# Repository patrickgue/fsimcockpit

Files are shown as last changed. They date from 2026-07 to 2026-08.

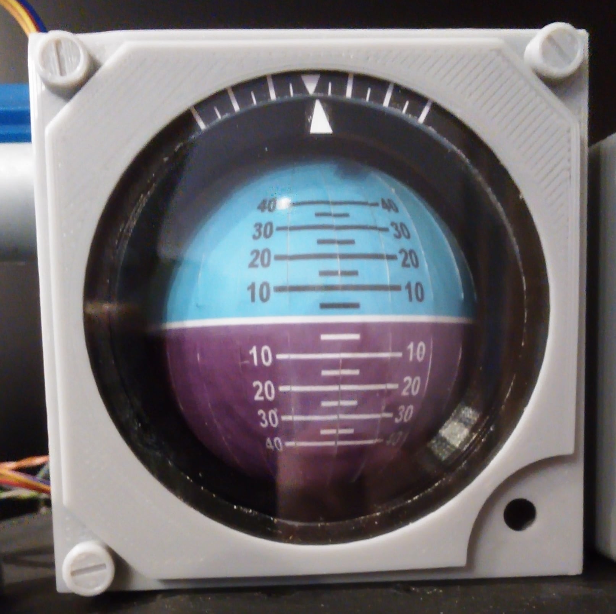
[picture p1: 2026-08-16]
Models/ai/images/Attitude_Indicator_printed.jpg

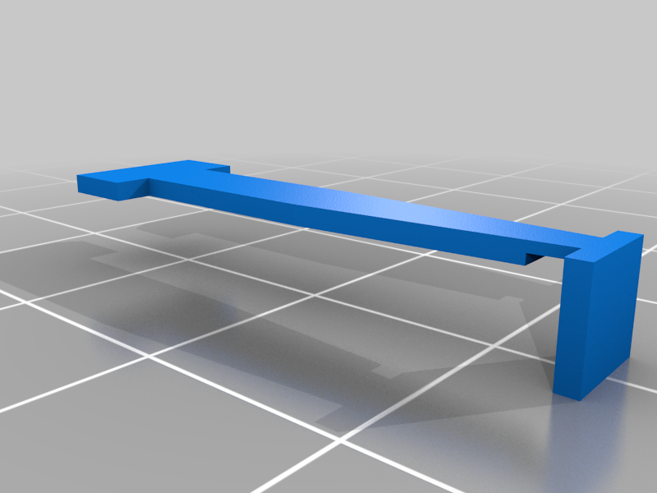
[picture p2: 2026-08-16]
Models/ai/images/964544c1647295031b2b73cd0fc1d7ba.png

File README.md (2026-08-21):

---
title: FSimCockpit
---

Software and Hardware for building a home cockpit with 3d printed "steam gauge" instruments

Components:

* Windows App: Connects to MSFS to read out instrument data. Send this data to the microcontroller via the serial connection. This is built using C# and provides a WPF GUI for instrument calibration.
* Microcontroller: Drive servos and stepper motors for the instrument. Arduino Mega based.
  * Parse instrument data from serial data coming from the windows application
* 3D models for printing, assembly

# Distribution

If not mentioned otherwise, this project is licensed under the MIT license. A copy of the license text is provided in the LICENSE file.

Following external components are used: (License file provided in the subfolder)

* Attitude Indicator (hein4bloed, CC-BY-NC)
* Vertical Speed indicator (Bacab, CC-BY-NC-SA)
* Turn coordinator (Bacab, CC-BY-NC-SA)

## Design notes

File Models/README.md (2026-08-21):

Servos and Steppers:

| **Instrument** | **Steppers** | **Servo** |
|---|---|---|
| VSI | 0 | 1 |
| HI | 1 | 0 |
| SPEED | 0 | 1 |
| ALT | 3 | 0 |
| TC | 0 | 2 |
| AI | 2 | 0 |

Sum: 5 Steppers, 4 Servos

## Vertical Speed Indicator (VSI)

Works as provided from thingiverse. Following things have to be added or modified:

* Adapter to connect gear to servo (`servo_gear_connector.scad`)
* Standoff; This is mentioned in the instruction. Either metal standoffs with threads can be used. Otherwise there are 3d printed standoffs provided (`Standoff.scad`)
* The hole on the front plate and the pointer have to be widened by grinding.

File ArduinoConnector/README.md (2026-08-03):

Data Table

| **Indication** | **Code** | **Description** |
|---|---:|---|
| VSI | 0x10 | vertical speed in ft/min |
| VSI_CALIBR_ZERO | 0x11 | in degrees (stepper) |
| VSI_CALIBR_PLUS5 | 0x12 | in degrees (stepper) |
| VSI_CALIBR_MINUS5 | 0x13 | in degrees (stepper) |
| HI | 0x20 | Heading Indicator in degrees |
| HI_CALIBR_ZERO, | 0x21 | in degrees (servo) |
| SPEED | 0x30 | airspeed in kt |
| SPEED_CALIBR_ZERO | 0x31 | in degrees (servo) |
| SPEED_CALIBR_HUNDRED | 0x32 | in degrees (servo) |
| ALT | 0x40 | altitude in ft |
| ALT_CALIBR_HUNDREDS_ZERO | 0x41 | in steps (stepper) |
| ALT_CALIBR_THOUSANDS_ZERO | 0x42 | in steps (stepper) |
| ALT_CALIBR_TENTHOUSANDS_ZERO | 0x43 | in steps (stepper) |
| TS_TURN | 0x50 | turn indicator in turns / 2*minute |
| TS_TURN_CALIBR_ZERO | 0x51 | in degrees (servo) |
| TS_TURN_CALIBR_LEFTTURN | 0x52 | in degrees (servo) |
| TS_TURN_CALIBR_RIGHTTURN | 0x53 | in degrees (servo) |
| TS_SLIP | 0x54 | slip indicator (-1.0 left, 1.0 right) |
| TS_SLIP_CALIBR_ZERO | 0x55 | in degrees (servo) |
| TS_SLIP_CALIBR_LEFT | 0x56 | in degrees (servo) |
| TS_SLIP_CALIBR_RIGHT | 0x57 | in degrees (servo) |
| AI_PITCH | 0x60 | attitude indicator (degrees) |
| AI_PITCH_CALIBR_20ZERO | 0x61 | in steps (stepper) |
| AI_PITCH_CALIBR_20UP | 0x62 | in steps (stepper) |
| AI_PITCH_CALIBR_20DOWN | 0x63 | in steps (stepper) |
| AI_ROL | 0x64 | attitude roll (degrees) |
| AI_ROL_CALIBR_20ZERO | 0x65 | in steps (stepper) |
| AI_ROL_CALIBR_20LEFT | 0x66 | in steps (stepper) |
| AI_ROL_CALIBR_20RIGHT | 0x67 | in steps (stepper) |
| ERROR | 0xFF | Invalid, should not occur |

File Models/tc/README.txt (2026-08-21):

Turn coordinator for flight simulator by Bacab on Thingiverse: https://www.thingiverse.com/thing:6554762

Summary:
This is a replica of a turn coordinator as can be found in nearly all general aviation aircrafts. It is designed to be used with two servo-motors (SG90 like)The PDF is the background to be printed and glued to the front plane.I will use it with an Arduino Uno. I plan on using it for DCS World through the use of DCS Bios.To assemble the different parts you will need 4 M3 screws (M3x10mm), 4 spacers (M3x30 mm) and four M3 nuts to attach the front face to the motor support. The servo-motors are attached using the M2 screws that came with them. You will also need a M2.5 screw to attach the ball (M2.5x5 mm) to the upper servo and one M2.5x20mm screw and two nuts to attach the aircraft to the second, lower, servo. The two nuts are used one against the other to block in the correct position the aircraft silhouette.

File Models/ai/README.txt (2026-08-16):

B737 Attitude Indicator by hein4bloed on Thingiverse: https://www.thingiverse.com/thing:1991135

Summary:
Use two 28BYJ-48 stepper motors and Arduino with Mobiflight Software. Works great!Read out FSX FSUIPC Pitch Offset 2F70 and Bank Offset 2F78.

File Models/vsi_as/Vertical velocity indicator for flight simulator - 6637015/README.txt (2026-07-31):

Vertical velocity indicator for flight simulator by Bacab on Thingiverse: https://www.thingiverse.com/thing:6637015

Summary:
This is a replica of a vertical velocity indicator as can be found in nearly all general aviation aircrafts. It is designed to be used with one servo-motor (SG90 like)The PDF is the background to be printed and glued to the front plate.I will use it with an Arduino Uno. I plan on using it for DCS World through the use of DCS Bios.To assemble the different parts you will need 4 M3 screws (M3x10mm), 4 M3 spacers (20mm) and 4 M3 nuts to attach the front face to the motor support. The servo-motor is attached using the M2 screws that came with it. You will also need a M2.5 screw to attach the servo gear (M2.5x5 mm) to the servo. The needle should be glued to the needle gear ONCE assembled with the front plate : the gear is on the back of the front plate, the needle on the other side.

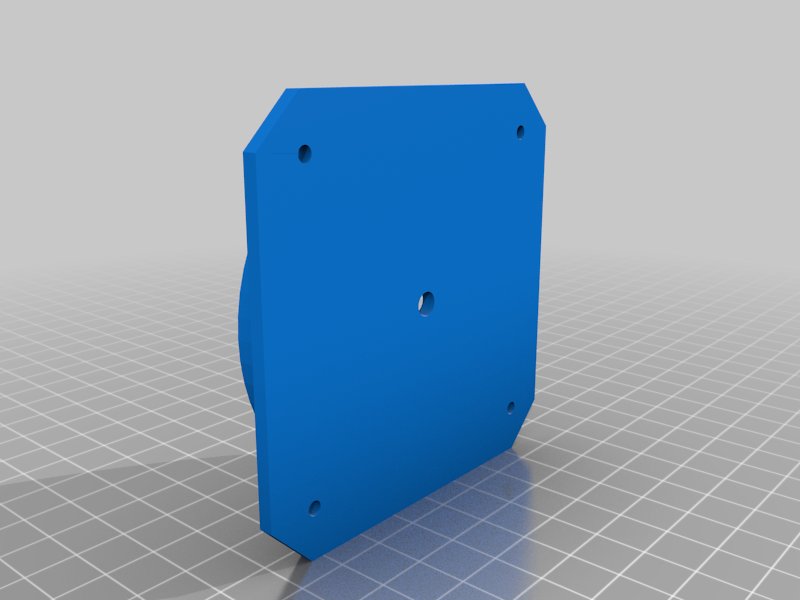
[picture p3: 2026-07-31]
Models/vsi_as/Vertical velocity indicator for flight simulator - 6637015/images/0cd2b5fc-27c4-4e6a-b78b-81af9a082db9.png

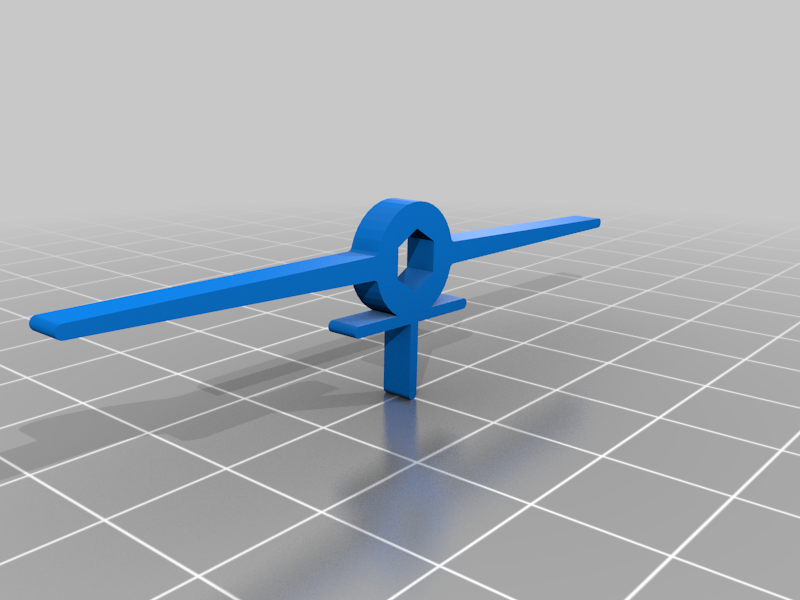
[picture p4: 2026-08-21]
Models/tc/images/5e0f1487-dd2c-4491-b8d7-2c6afee6cf06.png

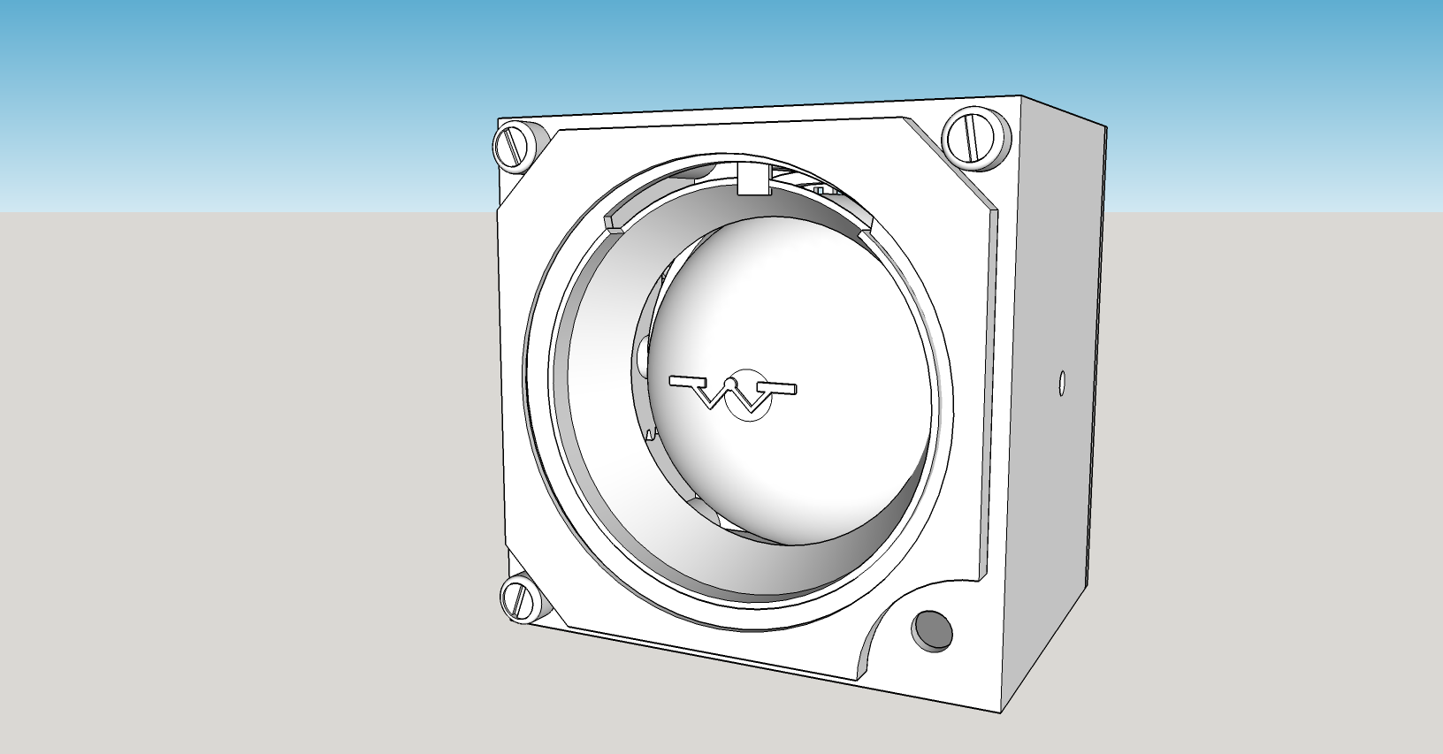
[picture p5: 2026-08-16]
Models/ai/images/Attitude_indicator1.png

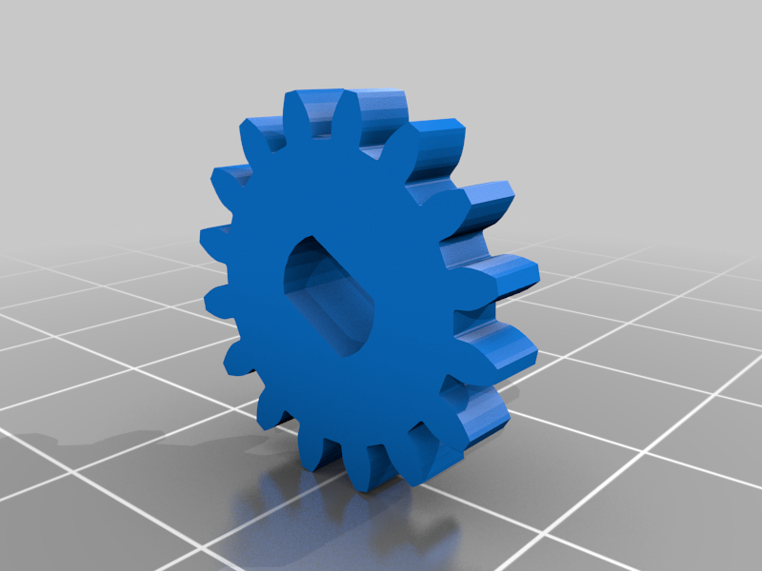
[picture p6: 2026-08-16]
Models/ai/images/55b75d970b0fac53f8fbcc01d031f647.png

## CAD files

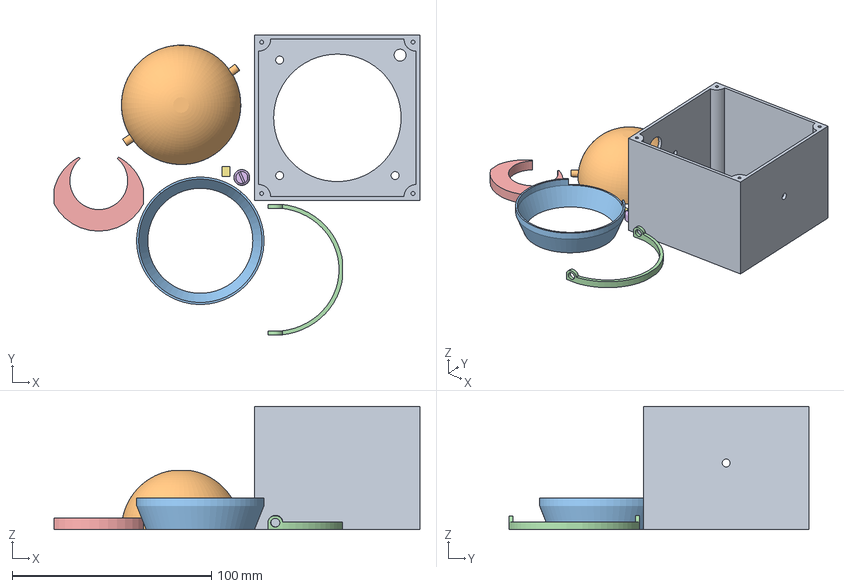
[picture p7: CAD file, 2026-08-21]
Models/ai/Attitude_indicator.3mf
183.8 x 150.5 x 62.0 mm
Gehaeuse.stl
Attitude_indicator.stl
Blende_innen.stl
Buegel.stl
Motorhalter.stl
Schraube.stl
Zeigerblaettchen.stl

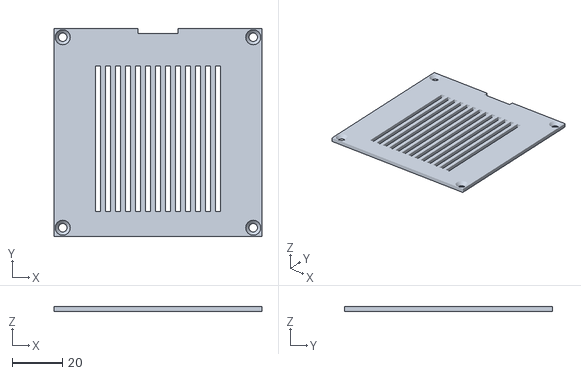
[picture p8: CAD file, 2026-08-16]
Models/ai/files/Rückwand.stl
83.0 x 83.0 x 2.00

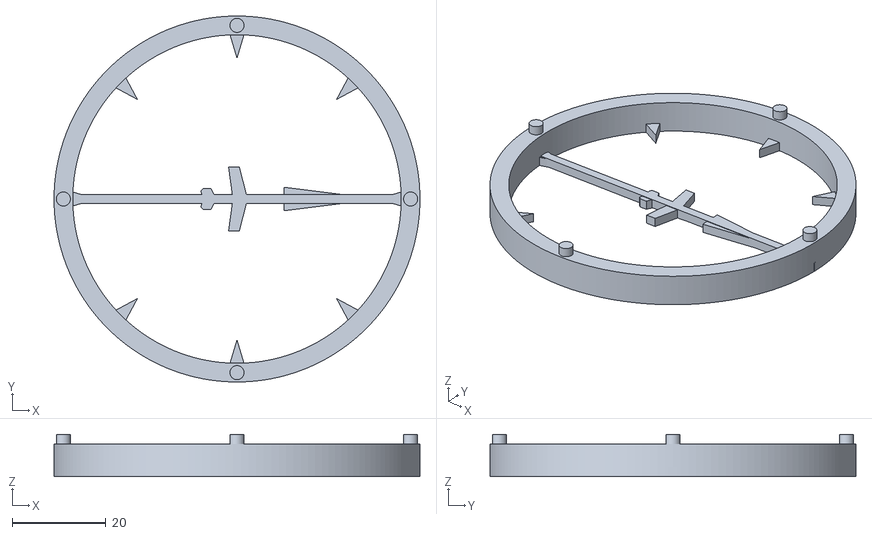
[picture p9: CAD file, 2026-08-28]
Models/hi/hi_face.stl
78.0 x 78.0 x 9.00

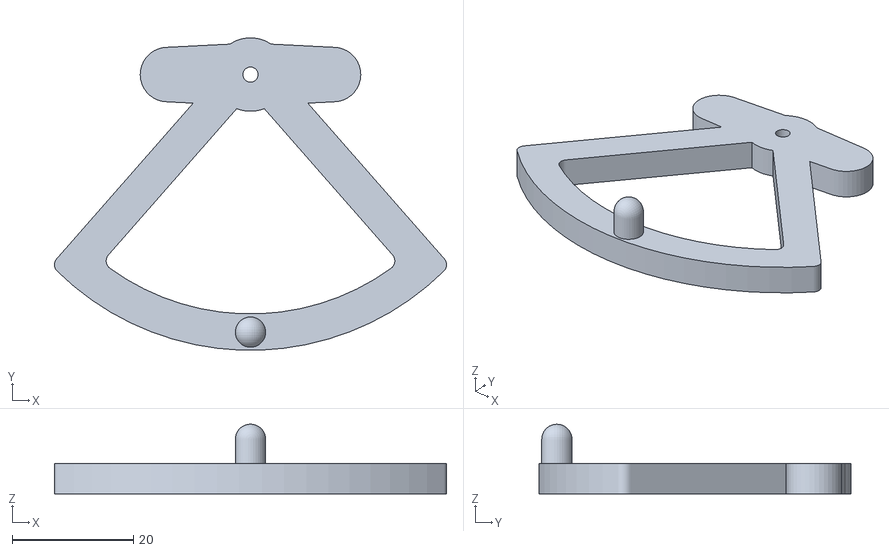
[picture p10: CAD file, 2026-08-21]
Models/tc/files/ball.STL
64.7 x 51.5 x 11.5

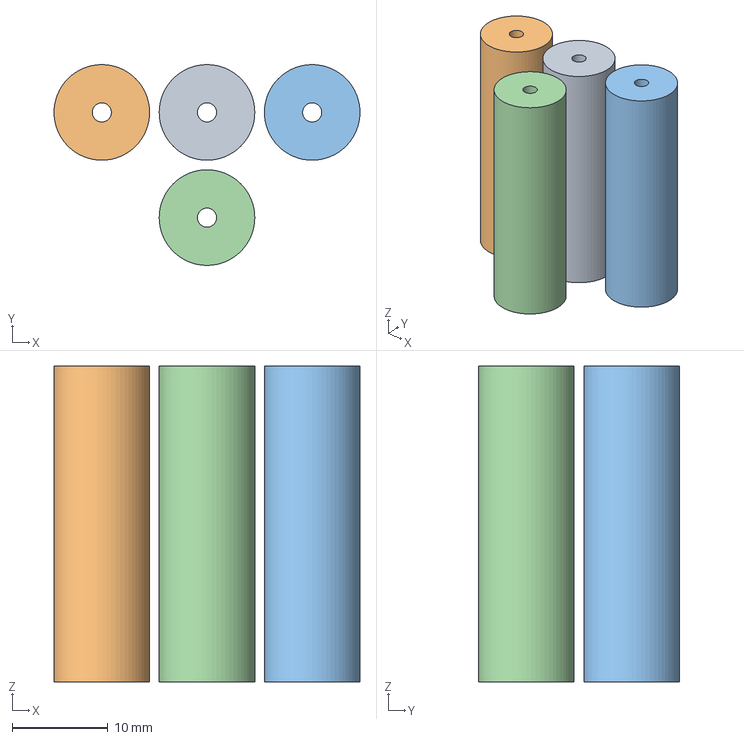
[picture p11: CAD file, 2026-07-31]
Models/vsi_as/standoffs.3mf
32.0 x 21.0 x 33.0 mm
standoffs.stl x 4

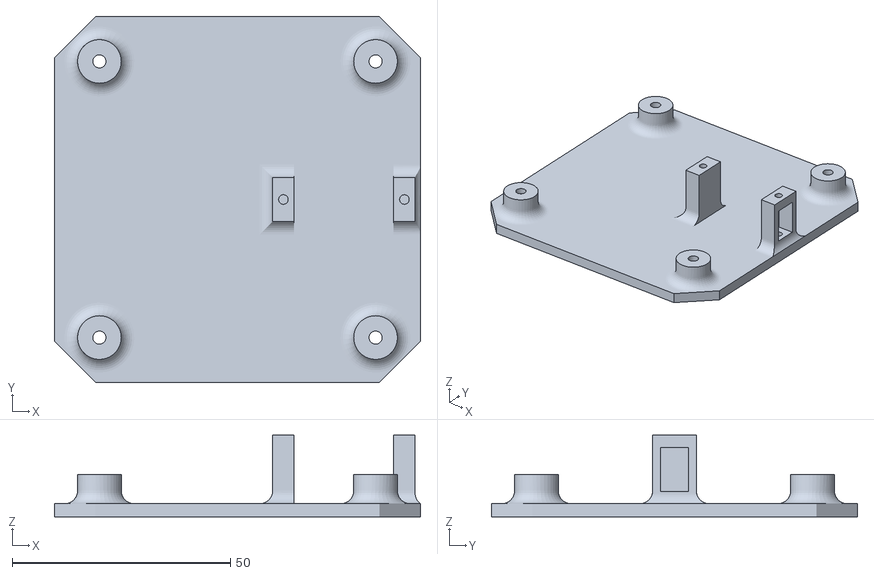
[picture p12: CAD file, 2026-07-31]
Models/vsi_as/Vertical velocity indicator for flight simulator - 6637015/files/back_plate_VVI.STL
83.8 x 83.8 x 18.7

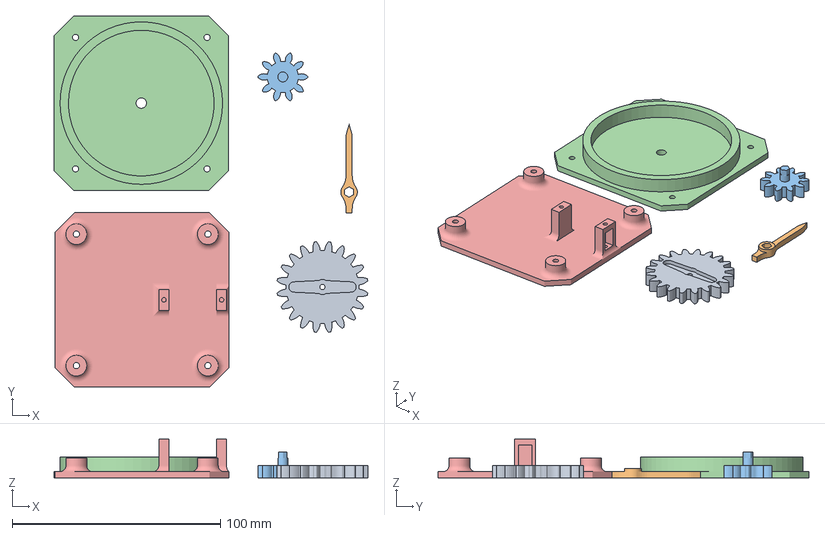
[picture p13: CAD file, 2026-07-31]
Models/vsi_as/Vertical velocity indicator for flight simulator - 6637015/servo_gear.3mf
150.8 x 178.4 x 18.7 mm
servo_gear.STL
needle_VVI.STL
needle_gear.STL
front_plate_VVI.STL
back_plate_VVI.STL

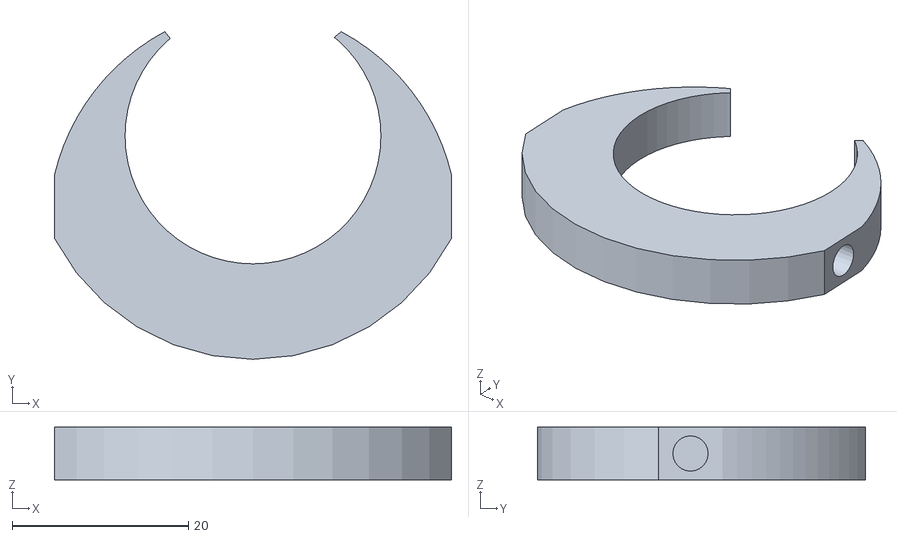
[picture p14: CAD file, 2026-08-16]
Models/ai/files/Motorhalter.stl
45.0 x 37.1 x 6.00

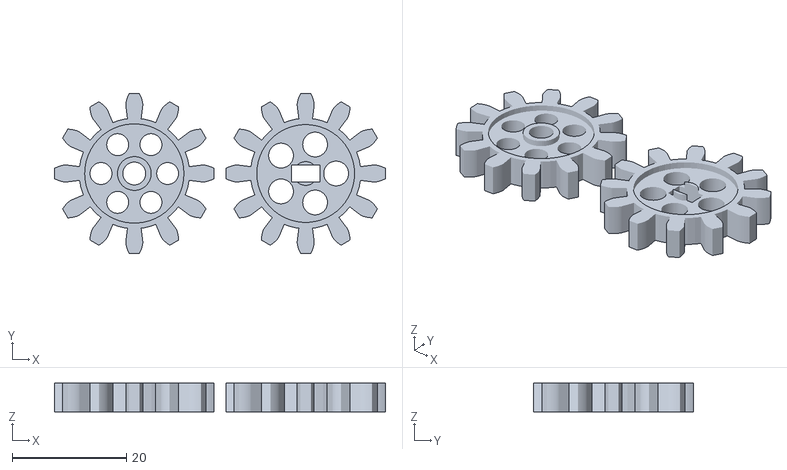
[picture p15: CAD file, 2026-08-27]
Models/hi/gear.stl
57.9 x 27.9 x 5.00

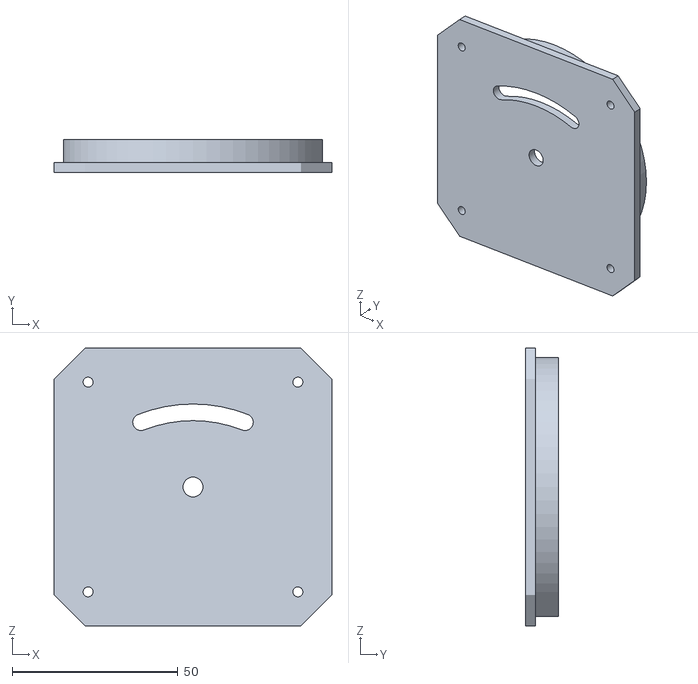
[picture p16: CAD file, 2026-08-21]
Models/tc/files/front_plane.STL
83.8 x 10.0 x 83.8

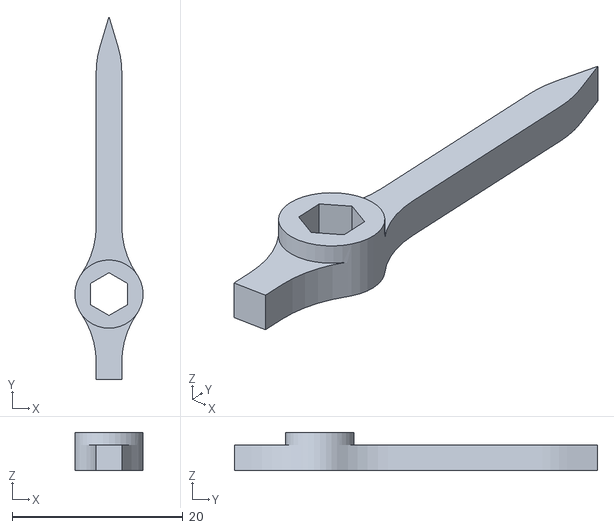
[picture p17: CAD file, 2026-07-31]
Models/vsi_as/Vertical velocity indicator for flight simulator - 6637015/files/needle_VVI.STL
8.00 x 42.5 x 4.50

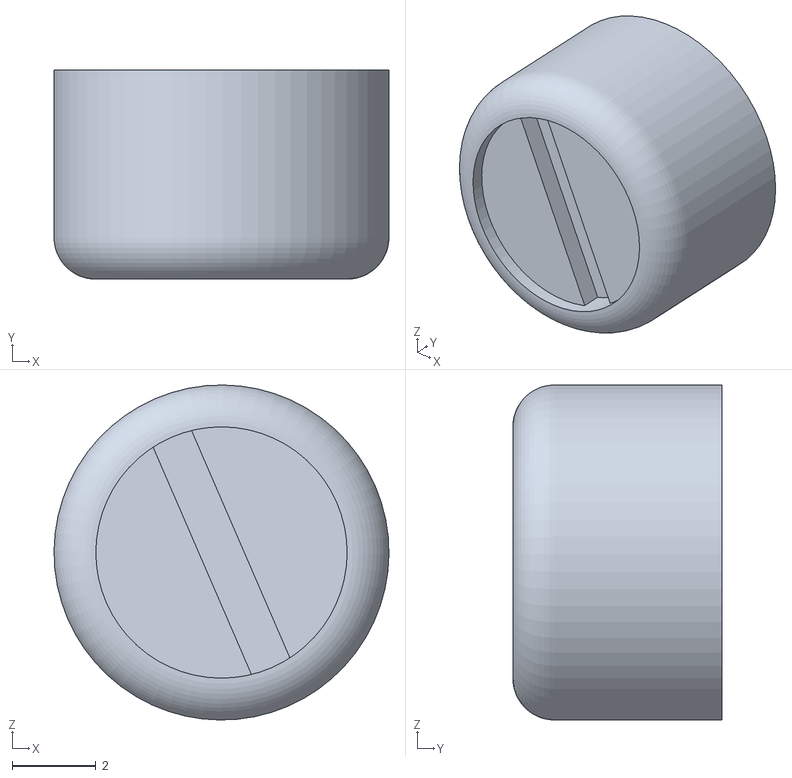
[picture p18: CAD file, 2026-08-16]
Models/ai/files/Schraube.stl
8.00 x 5.00 x 8.00

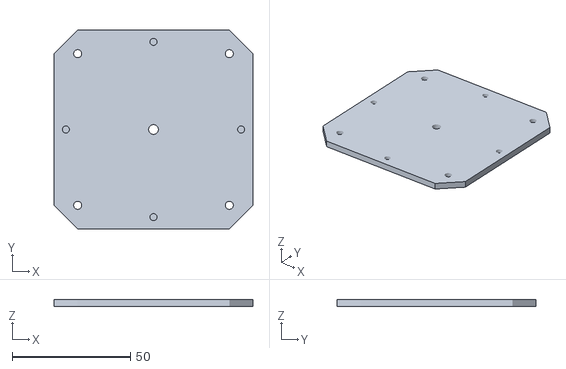
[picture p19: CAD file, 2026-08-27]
Models/hi/hi_front.stl
84.0 x 84.0 x 3.00

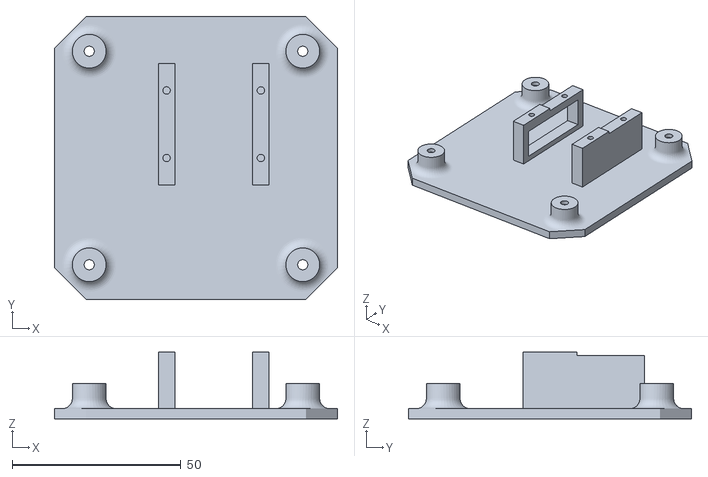
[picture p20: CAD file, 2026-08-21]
Models/tc/files/servo_support.STL
83.8 x 83.8 x 19.7

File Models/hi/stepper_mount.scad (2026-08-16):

$fn=30;

screw_offset=32;
stepper_screw_offset=35/2;
difference() {
    union() {
        // four main pillars
        for (i = [-screw_offset:2*screw_offset:screw_offset]) {

                translate([i, screw_offset, 0]) {
                    cylinder(d=6,h=7.5);
                }
        }
        // stepper mounting bracket
        translate([0,screw_offset + .5,4+(3.5/2)])
            cube([2*screw_offset + 6, 7, 3.5],center=true);
        
        
    }

    for (i = [-screw_offset:2*screw_offset:screw_offset]) {
        translate([i, screw_offset, 0])
            cylinder(d=3,h=8);
    }
    
    
    // additional space for gear
    translate([0,screw_offset,4])
        cube([28,8,2],center=true);
    
    for (i = [-stepper_screw_offset:2*stepper_screw_offset:stepper_screw_offset]) {
        translate([i, screw_offset + 1, 0])
            cylinder(d=3,h=8);
    }
}

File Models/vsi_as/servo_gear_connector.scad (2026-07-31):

$fn=60;

difference() {
union() {
cube([28,4,1], center= true);
translate([0,0,0.5])
cylinder(d=6.5,h=2,center=true);
translate([14,0,0])
    cylinder(d=4,h=1,center=true);
translate([-14,0,0])
    cylinder(d=4,h=1,center=true);
}
cylinder(d=2, h=4, center=true);
translate([0,0,1])
cylinder(d=4.8, h=1, center=true);
}

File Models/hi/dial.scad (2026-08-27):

$fn=150;
cylinder(d=68, h=1);
cylinder(d=3.8, h=8);

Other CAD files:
Models/vsi_as/Vertical velocity indicator for flight simulator - 6637015/files/front_plate_VVI.STL
Models/ai/files/Kugelstift.stl
Models/hi/dial.stl
Models/tc/files/aircraft.STL
Models/hi/gear.scad
Models/ai/files/Attitude_indicator.stl
Models/ai/files/Attitude_indicator1.skp
Models/ai/files/Blende_innen.stl
Models/ai/files/Buegel.stl
Models/ai/files/Frontblend.stl
Models/ai/files/Gehaeuse.stl
Models/ai/files/Horizontmarkierung.stl
Models/ai/files/Zahnrad1.stl
Models/ai/files/Zahnrad2.stl
Models/ai/files/Zeiger.stl
Models/ai/files/Zeigerblaettchen.stl
Models/alt/alt_A.3mf
Models/alt/alt_front.scad
Models/alt/alt_front.stl
Models/alt/alt_needle_100.scad
Models/alt/alt_needle_100.stl
Models/alt/alt_needle_1000.scad
Models/alt/alt_needle_1000.stl
Models/alt/alt_needle_10000.scad
Models/alt/alt_needle_10000.stl
Models/alt/gear_100.scad
Models/alt/gear_100.stl
Models/alt/gear_1000.scad
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

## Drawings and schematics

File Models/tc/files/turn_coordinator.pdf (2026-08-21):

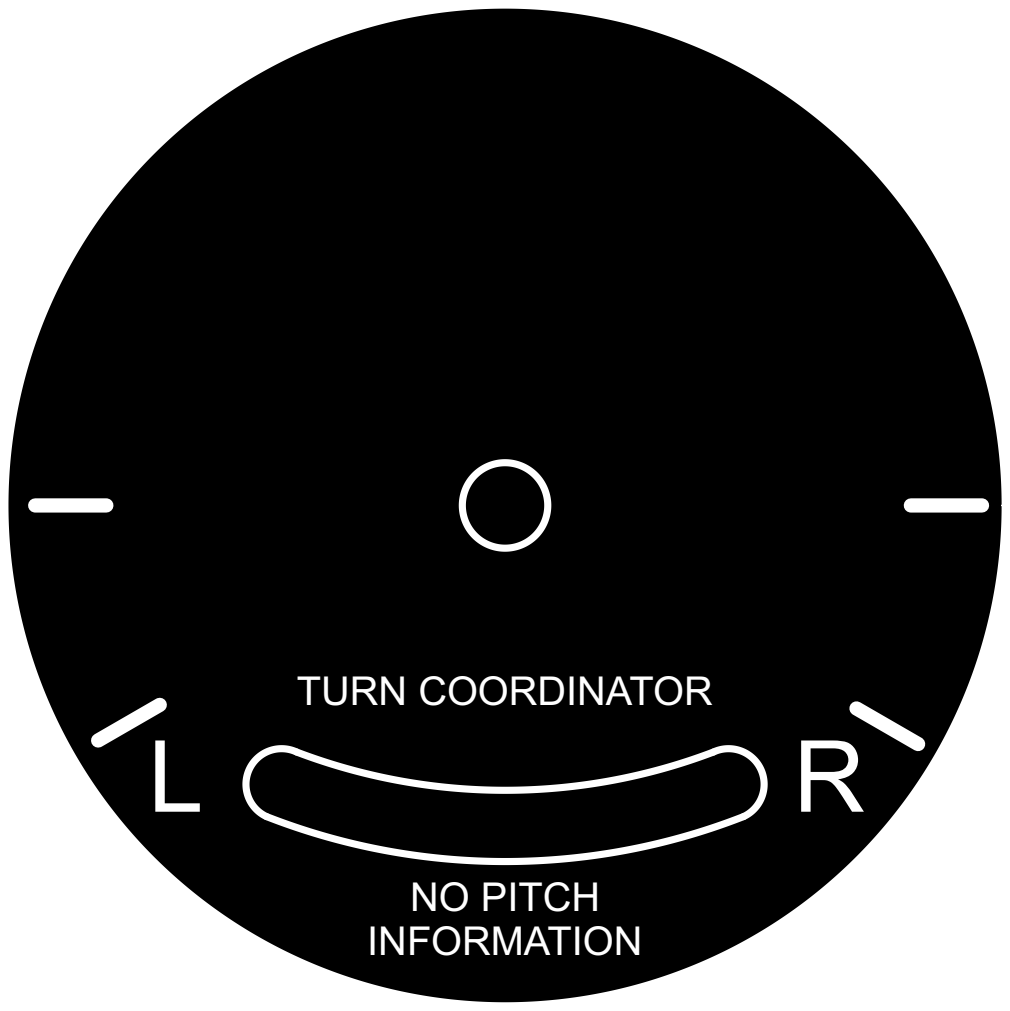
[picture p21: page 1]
TURN COORDINATOR; NO PITCH INFORMATION

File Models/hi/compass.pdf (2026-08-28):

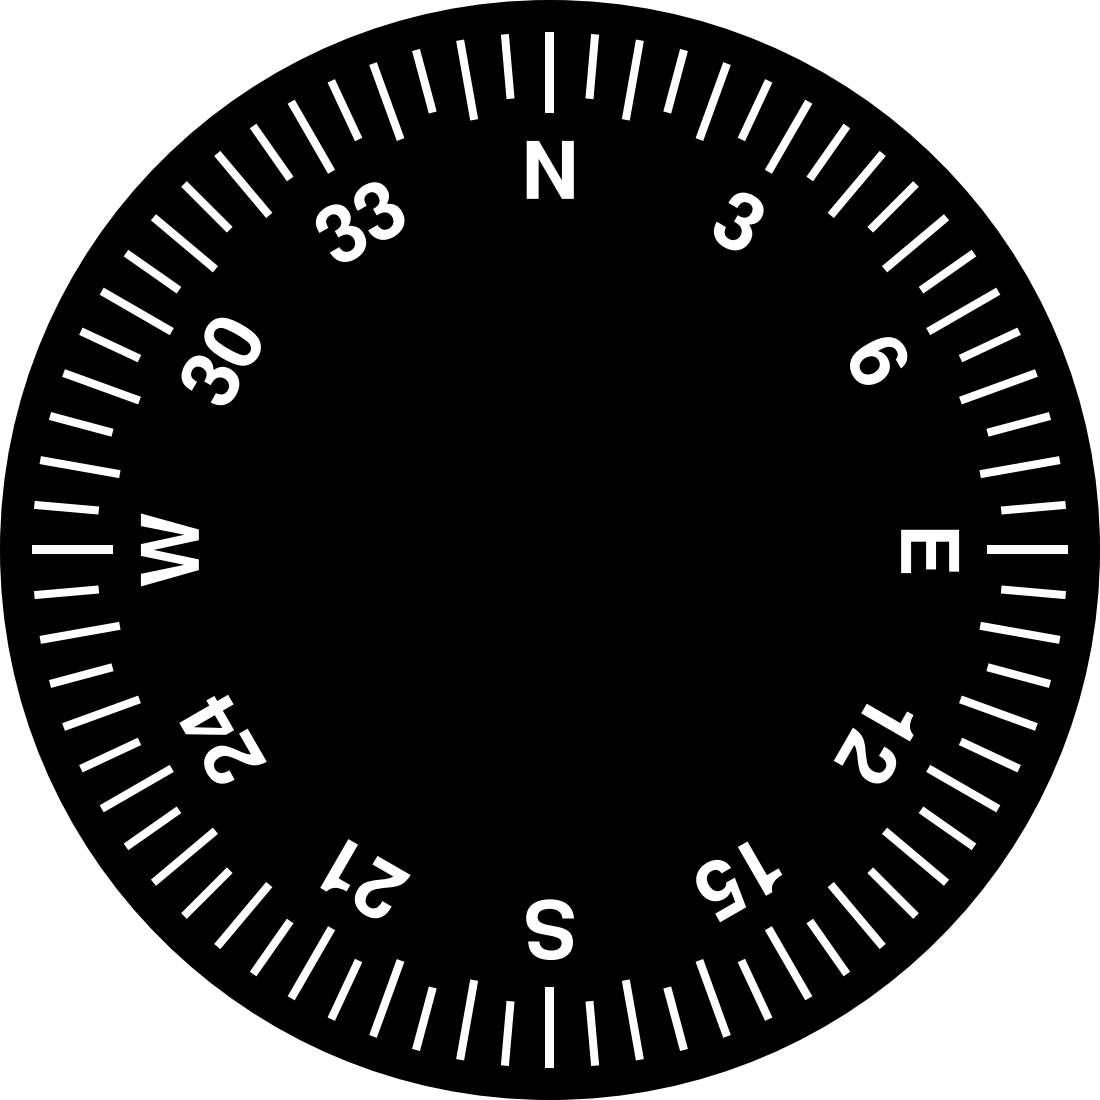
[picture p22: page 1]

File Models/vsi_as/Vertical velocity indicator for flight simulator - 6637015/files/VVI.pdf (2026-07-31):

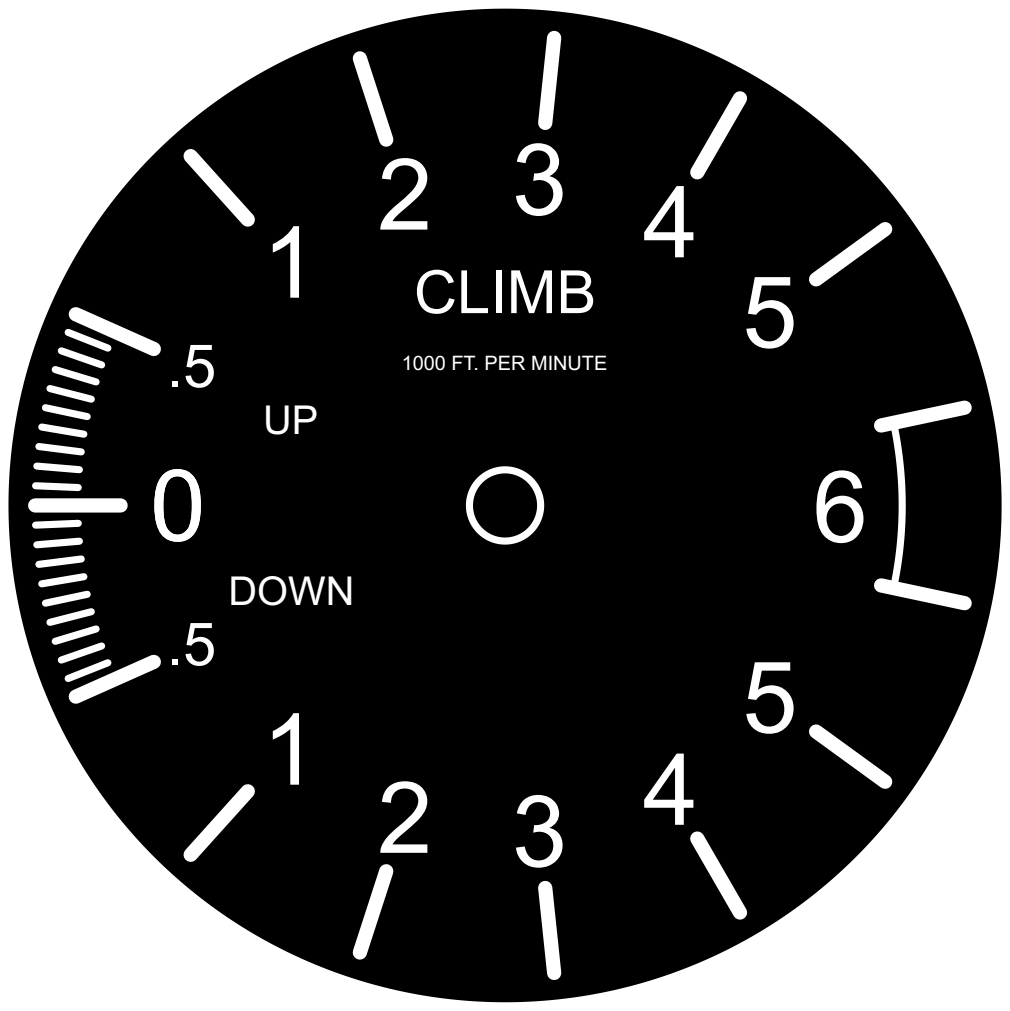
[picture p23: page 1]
6 .5 1 2 3 4 55 4 2 3 1 0 UP DOWN; 1000 FT. PER MINUTE CLIMB

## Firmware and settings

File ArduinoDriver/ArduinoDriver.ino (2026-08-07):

#include <math.h>

float vsi(float);
float hi(float);
float speed(float);
float alt100(float);
float alt1000(float);
float alt10000(float);
float ts_turn(float);
float ts_slip(float);
float ai_pitch(float);
float ai_roll(float);

#ifdef mock
#include <string.h>
#include "mock.h"
struct t_Serial Serial;
#else
#include <Servo.h>
#include <Stepper.h>
#endif

#include "codes.h"

/* Stepper */
#define OUTPUT1   6                // Connected to the Blue coloured wire
#define OUTPUT2   7                // Connected to the Pink coloured wire
#define OUTPUT3   8                // Connected to the Yellow coloured wire
#define OUTPUT4   9                // Connected to the Orange coloured wire

const int stepsPerRotation = 2048;  // 28BYJ-48 has 2048 steps per rotation in full step mode as given in data sheet

#ifdef mock

Stepper
HI_Step("HI"),
SPEED_Step("SPEED"),
ALT100_Step("ALT100"),
ALT1000_Step("ALT1000"),
ALT10000_Step("ALT10000"),
AI_PITCH_Step("AI_PITCH"),
AI_ROLL_Step("AI_ROLL");

#else

Stepper myStepper(stepsPerRotation, OUTPUT1, OUTPUT3, OUTPUT2, OUTPUT4);

#endif
/* Servo */
#ifdef mock
Servo
VSI_Servo("VSI"),
TS_TURN_Servo("TS_TURN"),
TS_SLIP_Servo("TS_SLIP");
#else
Servo
VSI_Servo, TS_TURN_Servo, TS_SLIP_Servo;
#endif
// twelve servo objects can be created on most boards


int pos = 0;    // variable to store the servo position
const int del = 30;


typedef unsigned char byte;



typedef union
{
    byte bytes[4];
    float f;
} float_parts;

byte buffer[5];
float_parts fltbuf;
byte code;

typedef struct
{
    float vsi;
    float hi;
    float speed;
    float alt, alt_100, alt_1000, alt_10000;
    float ts_turn, ts_slip;
    float ai_pitch, ai_roll;
} ServoState;

typedef struct
{
    float vsi_calibr_zero;
    float vsi_calibr_plus5;
    float vsi_calibr_minus5;
    float hi_calibr_zero;
    float speed_calibr_zero;
    float speed_calibr_hundred;
    float alt_calibr_hundreds_zero;
    float alt_calibr_thousands_zero;
    float alt_calibr_tenthousands_zero;
    float ts_turn_calibr_zero;
    float ts_turn_calibr_leftturn;
    float ts_turn_calibr_rightturn;
    float ts_slip_calibr_zero;
    float ts_slip_calibr_left;
    float ts_slip_calibr_right;
    float ai_pitch_calibr_zero;
    float ai_pitch_calibr_20up;
    float ai_pitch_calibr_20down;
    float ai_rol_calibr_zero;
    float ai_rol_calibr_20right;
    float ai_rol_calibr_20left;
} ServoCalibration;

ServoState State;
ServoCalibration Calibration;

void setup() {
    VSI_Servo.attach(3);  // attaches the servo on pin 7
    //myStepper.setSpeed(15);
    Serial.begin(9600);
}

void loop()
{

    if (Serial.available())
    {
        Serial.readBytes((char*)buffer, 5);
        code = buffer[0];
        memcpy(fltbuf.bytes, buffer + 1, 4);

        switch (code)
        {
        case VSI:
            State.vsi = vsi(fltbuf.f);
            break;
        case VSI_CALIBR_ZERO:
            State.vsi = fltbuf.f;
            Calibration.vsi_calibr_zero = fltbuf.f;
            break;
        case VSI_CALIBR_MINUS5:
            State.vsi = fltbuf.f;
            Calibration.vsi_calibr_minus5 = fltbuf.f;
            break;

        case HI:
            State.hi = hi(fltbuf.f);
            break;
        case HI_CALIBR_ZERO:
            State.hi = fltbuf.f;
            Calibration.hi_calibr_zero = fltbuf.f;
            break;

        case SPEED:
            State.speed = speed(fltbuf.f);
            break;
        case SPEED_CALIBR_ZERO:
            State.speed = fltbuf.f;
            Calibration.speed_calibr_zero = fltbuf.f;
            break;
        case SPEED_CALIBR_HUNDRED:
            State.speed = fltbuf.f;
            Calibration.speed_calibr_hundred = fltbuf.f;
            break;

        case ALT:
            State.alt = fltbuf.f;
            State.alt_100 = alt100(State.alt);
            State.alt_1000 = alt1000(State.alt);
            State.alt_10000 = alt10000(State.alt);
            break;
        case ALT_CALIBR_HUNDREDS_ZERO:
            State.alt = fltbuf.f;
            Calibration.alt_calibr_hundreds_zero = fltbuf.f;
            break;
        case ALT_CALIBR_THOUSANDS_ZERO:
            State.alt = fltbuf.f;
            Calibration.alt_calibr_thousands_zero = fltbuf.f;
            break;

        case TS_TURN:
            State.ts_turn = ts_turn(fltbuf.f);
            break;
        case TS_TURN_CALIBR_ZERO:
            State.ts_turn = fltbuf.f;
            Calibration.ts_turn_calibr_zero = fltbuf.f;
            break;
        case TS_TURN_CALIBR_LEFTTURN:
            State.ts_turn = fltbuf.f;
            Calibration.ts_turn_calibr_leftturn = fltbuf.f;
            break;
        case TS_TURN_CALIBR_RIGHTTURN:
            State.ts_turn = fltbuf.f;
            Calibration.ts_turn_calibr_rightturn = fltbuf.f;
            break;

        case TS_SLIP:
            State.ts_slip = ts_slip(fltbuf.f);
            break;
        case TS_SLIP_CALIBR_ZERO:
            State.ts_slip = fltbuf.f;
            Calibration.ts_slip_calibr_zero = fltbuf.f;
            break;
        case TS_SLIP_CALIBR_LEFT:
            State.ts_turn = fltbuf.f;
            Calibration.ts_slip_calibr_left = fltbuf.f;
            break;
        case TS_SLIP_CALIBR_RIGHT:
            State.ts_turn = fltbuf.f;
            Calibration.ts_slip_calibr_right = fltbuf.f;
            break;

        case AI_PITCH:
            State.ai_pitch = ai_pitch(fltbuf.f);
            break;
        case AI_PITCH_CALIBR_ZERO:
            State.ai_pitch = fltbuf.f;
            Calibration.ai_pitch_calibr_zero = fltbuf.f;
            break;
        case AI_PITCH_CALIBR_20UP:
            State.ai_pitch = fltbuf.f;
            Calibration.ai_pitch_calibr_20up = fltbuf.f;
        case AI_PITCH_CALIBR_20DOWN:
            State.ai_pitch = fltbuf.f;
            Calibration.ai_pitch_calibr_20down = fltbuf.f;

        case AI_ROLL:
            State.ai_roll = ai_roll(fltbuf.f);
            break;
        case AI_ROLL_CALIBR_ZERO:
            State.ai_roll = fltbuf.f;
            Calibration.ai_rol_calibr_zero = fltbuf.f;
            break;
        case AI_ROLL_CALIBR_20LEFT:
            State.ai_roll = fltbuf.f;
            Calibration.ai_rol_calibr_20left = fltbuf.f;
            break;
        case AI_ROLL_CALIBR_20RIGHT:
            State.ai_roll = fltbuf.f;
            Calibration.ai_rol_calibr_20right = fltbuf.f;
            break;
        }

    }
    VSI_Servo.write(State.vsi);
    TS_TURN_Servo.write(State.ts_turn);
    TS_SLIP_Servo.write(State.ts_slip);
    //HI_Step.
}

void loop2() {
    // goes from 0 degrees to 180 degrees
    for (pos = 0; pos <= 180; pos += 1) {
        VSI_Servo.write(pos);    // tell servo to go to position in variable 'pos'
        delay(del);               // waits 15ms for the servo to reach the position
    }
    //  myStepper.step(stepsPerRotation);
    delay(500);
    // goes from 180 degrees to 0 degrees
    for (pos = 180; pos >= 0; pos -= 1) {
        VSI_Servo.write(pos);    // tell servo to go to position in variable 'pos'
        delay(del);               // waits 15ms for the servo to reach the position
    }
    //  myStepper.step(-stepsPerRotation);
    delay(500);
}



#ifdef mock
int main()
{
    init_mock_serial(&Serial);
    setup();
    while (FOREVER)
    {
        loop();
    }
}
#endif


float vsi(float value)
{
    float res = Calibration.vsi_calibr_zero, delta;

    if (value > 0)
    {
        delta = Calibration.vsi_calibr_plus5 - res;
        return res + ((value / 5.0) * delta);
    }
    else
    {
        delta = res - Calibration.vsi_calibr_minus5;
        return res + ((value / 5.0) * delta);
    }
}

float hi(float value)
{
    return Calibration.hi_calibr_zero + value;
}

float speed(float speed)
{
    float base = Calibration.speed_calibr_zero;
    float delta = Calibration.speed_calibr_hundred - base;
    return base + ((speed / 100.0) * delta);
}

float alt100(float value)
{
    float alt = fmod(value, 1000);
    return Calibration.alt_calibr_hundreds_zero + (alt * 360.0 / 1000.0);
}

float alt1000(float value)
{
    float alt = fmod(value, 10000);
    return Calibration.alt_calibr_hundreds_zero + (alt * 360.0 / 10000.0);
}

float alt10000(float value)
{
    float alt = fmod(value, 100000);
    return Calibration.alt_calibr_hundreds_zero + (alt * 360.0 / 100000.0);
}

float ts_turn(float value)
{
    float base = Calibration.ts_turn_calibr_zero, delta;
    if (value > 0) // right
    {
        delta = Calibration.ts_turn_calibr_rightturn - base;
    }
    else // left
    {
        delta = base - Calibration.ts_turn_calibr_leftturn;
    }
    return base + (value * delta);
}


float ts_slip(float value)
{
    float base = Calibration.ts_slip_calibr_zero, delta;
    if (value > 0) // right
    {
        delta = Calibration.ts_slip_calibr_right - base;
    }
    else // left
    {
        delta = base - Calibration.ts_slip_calibr_left;
    }
    return base + (value * delta);
}

float ai_pitch(float value)
{
    float base = Calibration.ai_pitch_calibr_zero, delta;
    if (value > 0) // up
    {
        delta = Calibration.ai_pitch_calibr_20up - base;
    }
    else // down
    {
        delta = base - Calibration.ai_pitch_calibr_20down;
    }
    return base + ((value / 20.0) * delta);
}


float ai_roll(float value)
{
    float base = Calibration.ai_rol_calibr_zero, delta;
    if (value > 0) // right
    {
        delta = Calibration.ai_rol_calibr_20right - base;
    }
    else // left
    {
        delta = base - Calibration.ai_rol_calibr_20left;
    }
    return base + ((value / 20.0) * delta);
}

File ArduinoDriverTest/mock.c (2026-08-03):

#include <stdio.h>
#include <unistd.h>

#include "mock.h"

/****************
 * MOCK STEPPER *
 ****************/

void stepper_setSpeed(int speed)
{
    printf("STEPPER setSpeed %d\n", speed);
}

void init_mock_stepper(Stepper *stepper)
{
    stepper->setSpeed = stepper_setSpeed;
}


/**************
 * MOCK SERVO *
 **************/

void servo_attach(int pin)
{
    printf("SERVO attach on Pin %d\n", pin);
}

void servo_write(int degr)
{
    printf("SERVO write %d degr\n", degr);
}

void init_mock_servo(Servo *servo)
{
    servo->attach = servo_attach;
    servo->write = servo_write;
}

/***************
 * MOCK SERIAL *
 ***************/

void serial_begin(int baud)
{
    printf("SERIAL begin with baud rate %d\n", baud);
}

int serial_parseInt()
{
    return 10;
}

bool serial_available()
{
    return true;
}

void serial_readBytes(char *buffer, int c)
{
    int i;
    for (i = 0; i < c; i++)
    {
        buffer[i] = i;
    }
}

void serial_println(int i, enum e_SerialPrintMode mode)
{
    switch (mode)
    {
    case HEX:
        printf("SERIAL %x\n", i);
        break;
    case DEC:
        printf("SERIAL %d\n", i);
        break;
    }
}


void init_mock_serial(struct t_Serial *ser)
{
    ser->available = serial_available;
    ser->begin = serial_begin;
    ser->parseInt = serial_parseInt;
    ser->println = serial_println;
    ser->readBytes = serial_readBytes;
}


void delay(int d)
{
    usleep(d * 1000);
}

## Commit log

2026-07-31 add 3d models
    [Standoff.scad, back_plate_VVI.STL, front_plate_VVI.STL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]
2026-08-02 Rename arduino driver directory
2026-08-02 Change Models directory name
    [Standoff.scad, back_plate_VVI.STL, front_plate_VVI.STL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]
2026-08-02 Add library for serial link to arduino
2026-08-03 Add AI model
    [Abschluss-Blende.stl, Adapter.stl, Anschlag_und_kabelfuehrung.stl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]
2026-08-03 introduce servo states
2026-08-06 Restructure arduino project to circumvent weird compilation rules
2026-08-06 implement axis calculation using calibration data
2026-08-08 Design & generate needles for altimeter
    [alt_front.scad, alt_needle_100.scad, alt_needle_1000.scad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]
2026-08-09 Successfully tested with arduino USB serial device on NT
2026-08-14 modify altimeter parts, add gears
    [alt_front.scad, alt_front.stl, alt_needle_100.scad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]
2026-08-16 replace AI model with one better suited from thingiverse. Update attribution and license info
    [Abschluss-Blende.stl, Adapter.stl, Anschlag_und_kabelfuehrung.stl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]
2026-08-16 Design mounts for stepper motors in altitude indicator
    [alt_A.3mf, stepper_mount_100.scad, stepper_mount_100.stl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]
2026-08-21 rename vsi to as (airspeed) as the same model can be used for both
    [Standoff.scad, back_plate_VVI.STL, front_plate_VVI.STL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]
2026-08-21 change servo and stepper count to reflect design decision
2026-08-21 Add creality print file
    [Attitude_indicator.3mf]
2026-08-21 Add turn coordinator to repo
    [aircraft.STL, ball.STL, front_plane.STL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]
2026-08-27 heading indicater design first draft
    [dial.scad, dial.stl, gear.scad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]
2026-08-28 update plane model
    [hi_face.scad, hi_face.stl]
